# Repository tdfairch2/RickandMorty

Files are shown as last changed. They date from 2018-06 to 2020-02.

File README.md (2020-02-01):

# RickandMorty
Integrating Software and Hardware, specifically the Arduino Uno and Adafruit Pro-Trinket

This project is centered around a device from the Adult Swim cartoon "Rick and Morty"

Pin locations, source file links and the functionality is all provided in the Portal Gun document

Code alterations that I implemented are in the sketch "portalGun.ino", located in the PortalGun-master folder.  My changes to the original source code are indicated with more detailed comments than were included in the original.....\\|/

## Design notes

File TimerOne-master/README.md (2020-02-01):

#TimerOne Library#

Paul Stoffregen's modified TimerOne.  This version provides 2 main benefits:

1: Optimized inline functions - much faster for the most common usage  
2: Support for more boards (including ATTiny85 except for the PWM functionality)

http://www.pjrc.com/teensy/td_libs_TimerOne.html

https://github.com/PaulStoffregen/TimerOne

Original code:

http://playground.arduino.cc/Code/Timer1

Open Source License

TimerOne is free software. You can redistribute it and/or modify it under
the terms of Creative Commons Attribution 3.0 United States License.
To view a copy of this license, visit

http://creativecommons.org/licenses/by/3.0/us/

Paul Stoffregen forked this version from an early copy of TimerOne/TimerThree
which was licensed "Creative Commons Attribution 3.0" and has maintained
the original "CC BY 3.0 US" license terms.

Other, separately developed updates to TimerOne have been released by other
authors under the GNU GPLv2 license.  Multiple copies of this library, bearing
the same name but distributed under different license terms, is unfortunately
confusing.  This copy, with nearly all the code redesigned as inline functions,
is provided under the "CC BY 3.0 US" license terms.

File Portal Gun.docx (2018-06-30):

# PortalGun

# *****All resources used were originally found at:

# https://www.thingiverse.com/thing:1100601 and from there the following link -

# https://github.com/pomeroyb/PortalGun

# I have altered the pin-outs as necessary to allow for more sounds and for better organization of the wiring*****

Code to control a Portal Gun (From Rick and Morty)

##Libraries Download and install the following libraries:

- ClickEncoder (https://github.com/0xPIT/encoder)
- Adafruit_GFX (https://github.com/adafruit/Adafruit-GFX-Library)
- Adafruit_LEDBackpack (https://github.com/adafruit/Adafruit-LED-Backpack-Library)

## Pin Definitions

If you deviate from the following definitions, you will have to change the firmware to account for that.

LED Display | Trinket Pro Pin
SCL | A5
SDA | A4
GND | GND
Vcc | 5V
Vi2c | 5V

Rotary Encoder | Trinket Pro Pin
A | A1
B | A0
GND | GND
Button | A2

LED | Trinket Pro Pin
Top Bulb | 13
Front Right | 12
Front Center | 11
Front Left | 10

## Installing Firmware

First, set up the Arduino IDE according to Adafruit (https://learn.adafruit.com/introducing-pro-trinket/setting-up-arduino-ide). Connect your Trinket Pro and make sure the bootloader is running, then click upload.

## Button Behavior

The rotary encoder has a click button, and we can detect a single click, a double click, and a hold.

- Single Click : Wakes the Trinket Pro from low power mode
- Double Click : Reset to dimension C137
- Hold : Turn off LEDs and put the Trinket Pro into a low power mode.

## Sound FX Pin Definitions

If you deviate from the following definitions, you will have to change the firmware to account for that.

FX Sound Board | Trinket Pro Pin | | Sound Effect Dimension Location For these locations you can use any sound file you want, I used VLC media files (.OGG) per the specifications by Adafruit
0 | | 0 | C136 – this is the value entered on the LED display
1 | | 1 | C135
2 | | 2 | C134
3 | | 3 | C133
4 | | 4 | C132
5 | | 5 | C131
6 | | 6 | C130
7 | | 7 | C129
8 | | 8 | C128
9 | | 9 | C127

The above listing of the pin connections between the Pro Trinket and the Sound Board is just for the sake of clarity. The small size of the main body of the Portal Gun imposed severe restrictions on the layout of the components. It was necessary to lay the boards next to each other, which allowed very few options for connections. The use of solid core wire, which by its nature is very stiff, further complicated the assembly process. So there are only six sound files in use, and the actual layout and pin connections are illustrated below.

Pro Trinket Sound Board

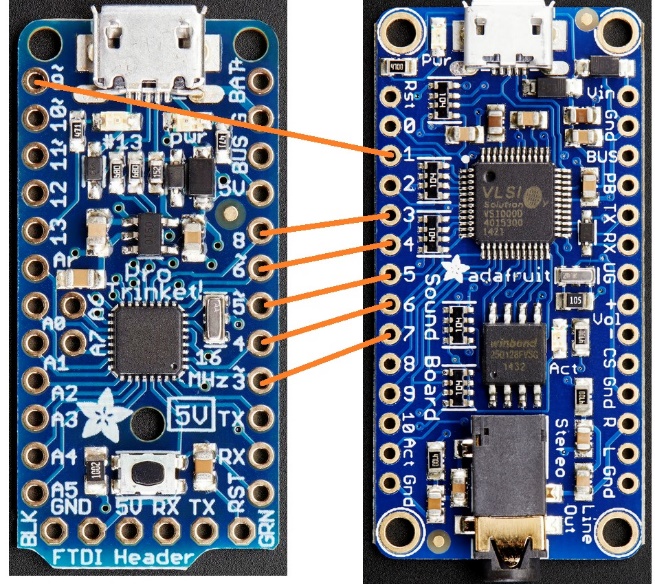
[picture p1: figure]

Wiring all of the components for this project proved to be quite a challenge.

The difficulties in assembling the circuit will probably be greatly reduced by soldering everything to a PCB instead of using wire.

## Installing Firmware

First, set up the Arduino IDE according to Adafruit (https://learn.adafruit.com/introducing-pro-trinket/setting-up-arduino-ide). Connect your Trinket Pro and make sure the bootloader is running, then click upload.

##Installing SFX You should be able to just connect the FX board to the computer, and drop the files in the "sfx" folder onto it. The files do follow a naming convention (see here (https://learn.adafruit.com/adafruit-audio-fx-sound-board/triggering-audio)), so don't change the file names unless you know what you're doing.

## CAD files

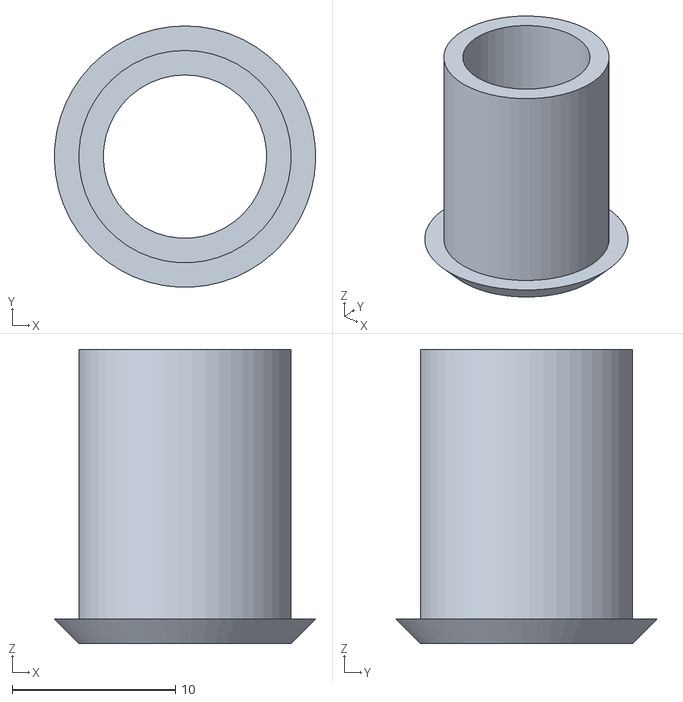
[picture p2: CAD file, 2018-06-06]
3-d print files/LEDHolder.STL
16.0 x 16.0 x 18.0

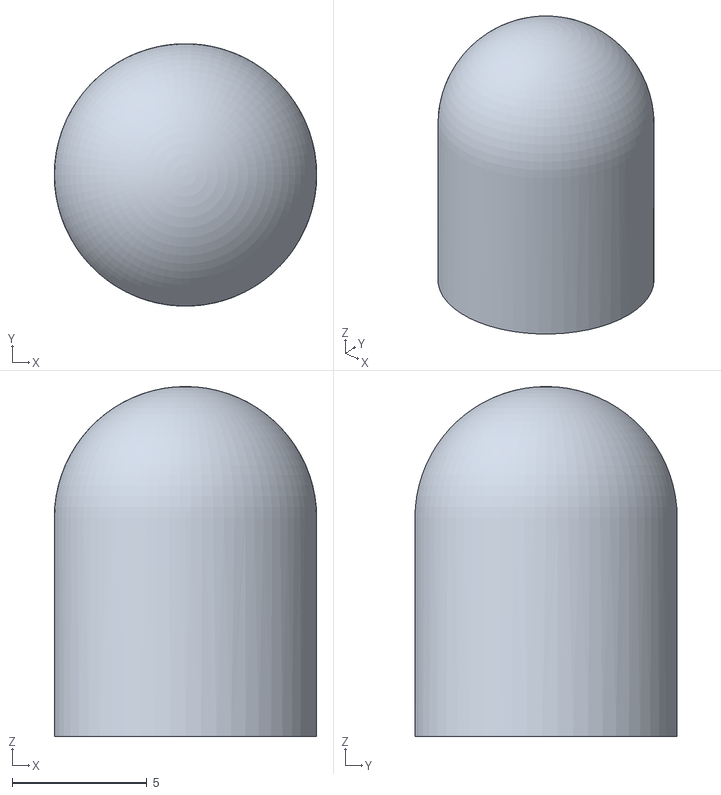
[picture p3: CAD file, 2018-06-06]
3-d print files/10mmLED.STL
9.75 x 9.75 x 13.0

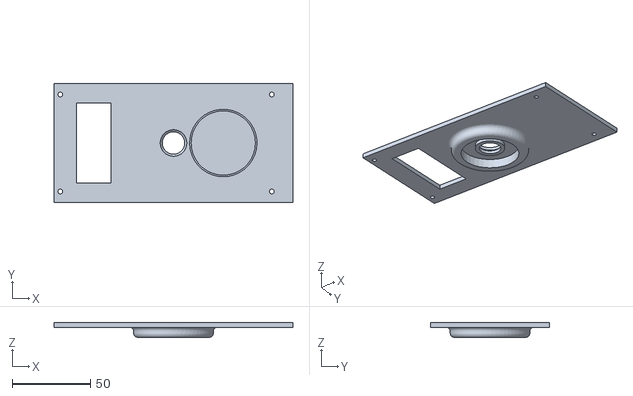
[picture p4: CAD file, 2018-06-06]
3-d print files/TopCover.stl
152.4 x 76.2 x 9.35

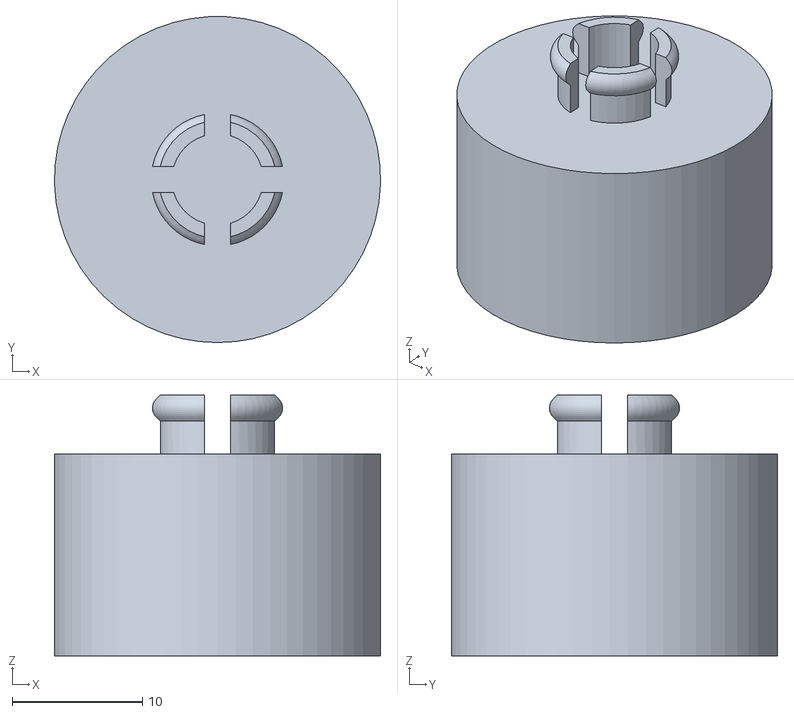
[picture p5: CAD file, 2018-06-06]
3-d print files/Knob.STL
25.0 x 25.0 x 20.0

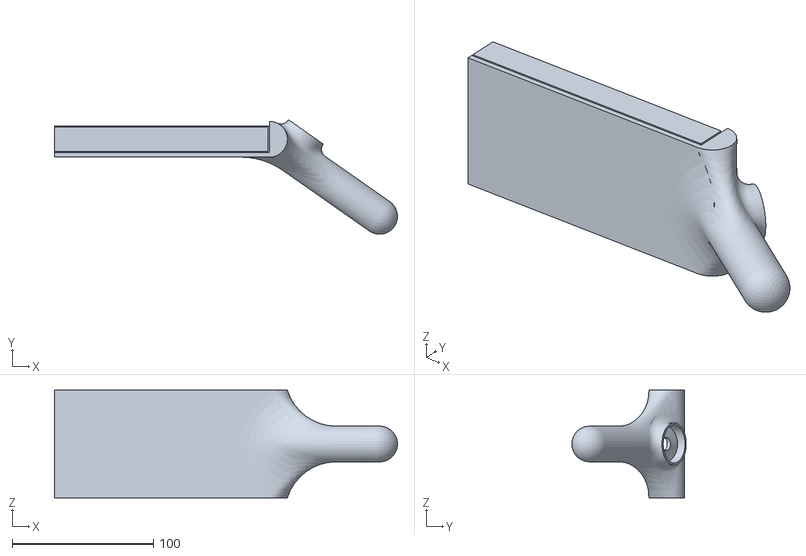
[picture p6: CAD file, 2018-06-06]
3-d print files/Body.stl
243.1 x 81.1 x 76.2

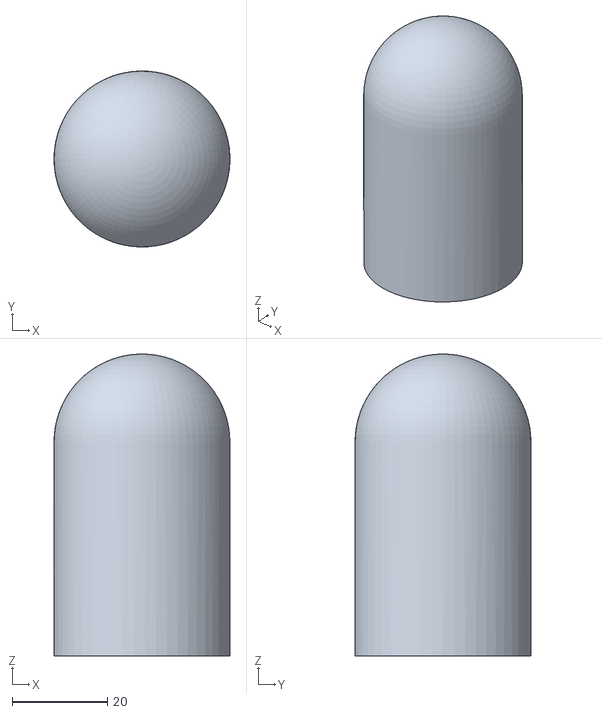
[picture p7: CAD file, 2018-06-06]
3-d print files/Bulb.stl
37.0 x 37.0 x 63.5

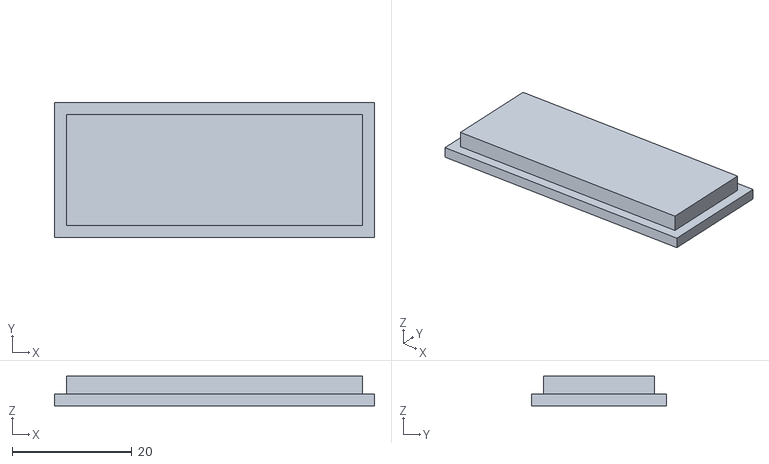
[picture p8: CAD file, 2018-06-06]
3-d print files/PrintedLEDScreen.STL
53.5 x 22.5 x 5.00

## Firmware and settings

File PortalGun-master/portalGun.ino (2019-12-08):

/* This is my very favorite project utilizing C++ programming.  I have created this repo as a record of my work but have made 
  updates to ensure inclusion in the GitHub Archive Progam, to have something as a legacy*/
#include <ClickEncoder.h>

#include <TimerOne.h>

// Code to control a Rick and Morty Portal Gun
// Written by Brandon Pomeroy, 2015

/* Modified by Terry Fairchild, 2018
  all 3-d print files and code source files -
  https://www.thingiverse.com/thing:1100601
      and -
  "People who are really serious about software should build their own hardware" - Alan Kay*/

/*
******** Required Libraries *************
  ClickEncoder - https://github.com/0xPIT/encoder
  Adafruit_GFX - https://github.com/adafruit/Adafruit-GFX-Library
  Adafruit_LEDBackpack - https://github.com/adafruit/Adafruit-LED-Backpack-Library
*/


/*
********** Required Hardware *********************
  Adafruit Pro Trinket 5V 16MHz - http://www.adafruit.com/product/2000
  LiPoly BackPack - http://www.adafruit.com/product/2124
  LiPoly Battety 3.7V - http://www.adafruit.com/products/1578
  Rotary Encoder - http://www.adafruit.com/products/377
  Metal Knob - http://www.adafruit.com/products/2056
  Quad Alphanumeric Display (Red 0.54") - http://www.adafruit.com/products/1911
  10mm Diffused Green LED (x4) - https://www.adafruit.com/products/844
  10mm Plastic Bevel LED Holder (x4) - https://www.adafruit.com/products/2171
  150 Ohm Resistor (x4) for LEDs
  Inductive Charging Set - 5V - https://www.adafruit.com/products/1407
  2.1mm Panel Mount Barrel Jack - http://www.adafruit.com/products/610
  9VDC Power Supply - http://www.adafruit.com/products/63
*/

#include <Wire.h>
#include "Adafruit_LEDBackpack.h"
#include "Adafruit_GFX.h"
#include <ClickEncoder.h>
#include <TimerOne.h>
#include <avr/sleep.h>
#include <avr/power.h>

// Set up our LED display
Adafruit_AlphaNum4 alpha4 = Adafruit_AlphaNum4();
char displayBuffer[4];
uint8_t dimensionLetter = 'C';

// Set up the click encoder
ClickEncoder *encoder;
int16_t last, value;
#define encoderPinA          A1
#define encoderPinB          A0
#define encoderButtonPin     A2

// Steps per notch can be 1, 4, or 8. If your encoder is counting
// to fast or too slow, change this!
#define stepsPerNotch        4

// Comment this line to make the encoder increment in the opposite direction
#define reverseEncoderWheel

// FX Board output delay (ms)
const int msDelay = 500;


/*************************************************************************************************************************************************************************
*                       Set up the sound fx pinouts
* The soundboard allows for only 10 ogg files because it has 10 output pins and the files stored in its memory are identified by number,
*  starting with 01 and ending with 10, depending on how many sound files are to be used.
* 
* 
* For the Pro Trinket, the sound file names are merely references.  I think they can be anything.  They are defined in the statements below.  
*    These names trigger the output pins to which they are assigned, listed next to them.
*
* The six Pro Trinket output pins available for sounds are pins 3 thru 9. Pin 8 is not labeled on the Pro Trinket so I skipped it.  For clarity each of the six pins used 
*    is connected to the corresponding numbered pin on the sound board.
*
* The numbered pin on the sound board plays whichever ogg file has that number.  i.e. sound file 'T04' is the name of an ogg audio file on the sound board.
*    Sound file T04 will be output whenever pin 04 on the sound board is triggered.  Pin 04 is connected to Trinket pin 4, and it is assigned to the variable name 'pickleRick'
*    in the sketch.  So when the sketch correctly uses the name 'pickleRick', it triggers pin 4 on the Pro Trinket which triggers pin 04 on the sound board, 
*    which causes ogg file T04 to play.
*
* Sound files T00, T01, T02, T08 and T10 are included on soundboard.  They have not been integrated into the code because I think there are fewer pinouts on the pro trinket
*    available for sound than were available on the Arduino board I used to prototype this project, and I did not wish to go to the effort to test this.
*
* Just make sure that 1) the pinouts on the Pro Trinket connect to the desired pinouts on the sound board and 2) the names of the sound files match the desired pinouts on the
*    sound board.  If you get either of these wrong you will not get the sound file you want for your dimension location
/*************************************************************************************************************************************************************************/
#define portalGunPin         3      //Portal, T03
#define pickleRick           4      //Pickle Rick, T04
#define tinyRick             5      //Tiny Rick, T05
#define peaceOot             6      //Peace oot, T06 
#define partyBiiiiitch       7      //Party bitch, T07
#define riggityWreckedSon    9      //Wrecked, T09
/************************************************************/
/************************************************************/


// Set up the Green LEDs
#define topBulbPin           13
#define frontRightPin        12
#define frontCenterPin       11
#define frontLeftPin         10
#define maximumBright        255
#define mediumBright         127
int topBulbBrightness = 255;

// Set up what we need to sleep/wake the Trinket
// Define the pins you'll use for interrupts - CHANGE THESE to match the input pins
// you are using in your project
#define NAV0_PIN A2
#define NAV1_PIN 1
#define NAV2_PIN 2


//Let us know if our Trinket woke up from sleep
volatile bool justWokeUp;


void timerIsr() {
  encoder->service();
}


void setup() {
  enablePinInterupt(NAV0_PIN);
  enablePinInterupt(NAV1_PIN);
  enablePinInterupt(NAV2_PIN);

  //Set up pin modes
  pinMode(topBulbPin, OUTPUT);
  pinMode(frontRightPin, OUTPUT);
  pinMode(frontLeftPin, OUTPUT);
  pinMode(frontCenterPin, OUTPUT);


/*************************************************************************/
/****Initialize the sound fx pinouts and topBulb to be output pins *******/
/*************************************************************************/
  pinMode(portalGunPin, OUTPUT);
  pinMode(pickleRick, OUTPUT);
  pinMode(tinyRick, OUTPUT);
  pinMode(peaceOot, OUTPUT);
  pinMode(partyBiiiiitch, OUTPUT);
  pinMode(riggityWreckedSon, OUTPUT);
/*************************************************************************/
/*************************************************************************/


  digitalWrite(frontRightPin, LOW);
  digitalWrite(frontLeftPin, LOW);
  digitalWrite(frontCenterPin, LOW);
  digitalWrite(topBulbPin, HIGH); //topBulbPin is for the plasma chamber and is illuminated until shutdown


/********************************************************************************
 * Initialize the sound fx pins to be OFF
 * Counter-intuitively when these pins are set to 'LOW' 
 * they become active, then become inactive when set to 'HIGH'.
 *******************************************************************************/
  digitalWrite(portalGunPin, HIGH);
  digitalWrite(pickleRick, HIGH);
  digitalWrite(tinyRick, HIGH);
  digitalWrite(peaceOot, HIGH);
  digitalWrite(partyBiiiiitch, HIGH);
  digitalWrite(riggityWreckedSon, HIGH);
/******************************************************************************
 ******************************************************************************/


  encoderSetup();
  alpha4.begin(0x70);  // pass in the address for the LED display

  justWokeUp = false;

}


void loop() {
  if (justWokeUp) {


/***************************************************************************
*  At 'wake-up', sound fx are turned off by setting to HIGH
* Seems redundant but otherwise they trigger constantly
***************************************************************************/
    digitalWrite(portalGunPin, HIGH);
    digitalWrite(pickleRick, HIGH);
    digitalWrite(tinyRick, HIGH);
    digitalWrite(peaceOot, HIGH);
    digitalWrite(partyBiiiiitch, HIGH);
    digitalWrite(riggityWreckedSon, HIGH);
/***************************************************************************/
/***************************************************************************/


    digitalWrite(frontRightPin, LOW);
    digitalWrite(frontLeftPin, LOW);
    digitalWrite(frontCenterPin, LOW);
    digitalWrite(topBulbPin, HIGH);
    justWokeUp = false;
  }

  ClickEncoder::Button b = encoder->getButton();
  switch (b) {
    case ClickEncoder::Held:
      // Holding the button will put your trinket to sleep.
      // The trinket will wake on the next button press
      alpha4.clear();
      alpha4.writeDigitAscii(0, 'R');
      alpha4.writeDigitAscii(1, 'I');
      alpha4.writeDigitAscii(2, 'C');
      alpha4.writeDigitAscii(3, 'K');
      digitalWrite(frontRightPin, LOW);
      digitalWrite(frontLeftPin, LOW);
      digitalWrite(frontCenterPin, LOW);
      digitalWrite(topBulbPin, LOW);


/***************************************************************************
*  At shut-down, sound fx are turned off
****************************************************************************/
      digitalWrite(portalGunPin, HIGH);
      digitalWrite(pickleRick, HIGH);
      digitalWrite(tinyRick, HIGH);
      digitalWrite(peaceOot, HIGH);
      digitalWrite(partyBiiiiitch, HIGH);
      digitalWrite(riggityWreckedSon, HIGH);
/***************************************************************************
***************************************************************************/


      alpha4.writeDisplay();
      delay(2000);
      alpha4.clear();
      alpha4.writeDisplay();


/**************************************************************************
*           Original code block above displayed "RICK" only
*  The following modification scrolls "RICK and MORTY" during shutdown
/**************************************************************************/
      alpha4.clear();
      alpha4.writeDigitAscii(0, 'a');
      alpha4.writeDigitAscii(1, 'n');
      alpha4.writeDigitAscii(2, 'd');
      alpha4.writeDigitAscii(3, ' ');
      alpha4.writeDisplay();
      delay(750);
      alpha4.clear();
      alpha4.writeDisplay();
      delay(500);

      alpha4.clear();
      alpha4.writeDigitAscii(0, 'M');
      alpha4.writeDigitAscii(1, 'O');
      alpha4.writeDigitAscii(2, 'R');
      alpha4.writeDigitAscii(3, 'T');
      alpha4.writeDisplay();
      delay(500);

      alpha4.clear();
      alpha4.writeDigitAscii(0, 'O');
      alpha4.writeDigitAscii(1, 'R');
      alpha4.writeDigitAscii(2, 'T');
      alpha4.writeDigitAscii(3, 'Y');
      alpha4.writeDisplay();
      delay(500);
      
      alpha4.clear();
      alpha4.writeDigitAscii(0, 'R');
      alpha4.writeDigitAscii(1, 'T');
      alpha4.writeDigitAscii(2, 'Y');
      alpha4.writeDigitAscii(3, ' ');
      alpha4.writeDisplay();
      delay(500);

      alpha4.clear();
      alpha4.writeDigitAscii(0, 'T');
      alpha4.writeDigitAscii(1, 'Y');
      alpha4.writeDigitAscii(2, ' ');
      alpha4.writeDigitAscii(3, ' ');
      alpha4.writeDisplay();
      delay(500);


      alpha4.clear();
      alpha4.writeDigitAscii(0, 'Y');
      alpha4.writeDigitAscii(1, ' ');
      alpha4.writeDigitAscii(2, ' ');
      alpha4.writeDigitAscii(3, ' ');
      alpha4.writeDisplay();
      delay(500);
      alpha4.clear();
      alpha4.writeDisplay();
      delay(1000);
/***********************************************************************************
************************************************************************************/


      justWokeUp = true;
      goToSleep();
      break;

    case ClickEncoder::Clicked:
      // When the encoder wheel is single clicked


/***************************************************************************************
* Check if this is a sound fx dimension
* Sound will trigger at specific locations when entered AND button is pressed once 
* File names are listed in the comments above when the sound files are defined 
* When triggered the output requires a delay of at least 200ms
***************************************************************************************/
      if (dimensionLetter == 'C' && value == 136){
                  delay (500);
                  digitalWrite(peaceOot, LOW);
                  delay (500);
                  digitalWrite(peaceOot, HIGH);
      }

      else if (dimensionLetter == 'C' && value == 135){
                  delay (500);
                  digitalWrite(tinyRick, LOW);
                  delay (500);
                  digitalWrite(tinyRick, HIGH);
      }
      else if (dimensionLetter == 'C' && value == 134){
                  delay (500);
                  digitalWrite(pickleRick, LOW);
                  delay (500);
                  digitalWrite(pickleRick, HIGH);
      }
      else if (dimensionLetter == 'C' && value == 133){
                  delay (500);
                  digitalWrite(partyBiiiiitch, LOW);
                  delay (500);
                  digitalWrite(partyBiiiiitch, HIGH);
      }
      else if (dimensionLetter == 'C' && value == 132){
                  delay (500);
                  digitalWrite(riggityWreckedSon, LOW);
                  delay (500);
                  digitalWrite(riggityWreckedSon, HIGH);
      }
/************************************************************************************
* If a sound fx location is not selected, run the Firing Sequence.
* Flash the LED's and the word FIRE five times simultaneously
*  then four times flash the LED's only  
************************************************************************************/
        else {                                              //
        digitalWrite(portalGunPin, LOW);                    //
        delay(500);                                         //
        digitalWrite(portalGunPin, HIGH);                   //
                                                            //
      for (int i = 1; i <= 5; i++) {                        //
        alpha4.clear();                                     //
        alpha4.writeDigitAscii(0, 'F');                     //
        alpha4.writeDigitAscii(1, 'I');                     //
        alpha4.writeDigitAscii(2, 'R');                     //
        alpha4.writeDigitAscii(3, 'E');                     //
        digitalWrite(frontRightPin, LOW);                   //
        digitalWrite(frontLeftPin, LOW);                    //
        digitalWrite(frontCenterPin, LOW);                  //
                                                            //
        alpha4.writeDisplay();                              //
        delay(250);                                         //
        alpha4.clear();                                     //
        digitalWrite(frontRightPin, HIGH);                  //
        digitalWrite(frontLeftPin, HIGH);                   //
        digitalWrite(frontCenterPin, HIGH);                 //
                                                            //
        alpha4.writeDisplay();                              //
        delay(250);                                         //
      }                                                     //
      for (int i = 1; i <= 4; i++) {                        //
        alpha4.clear();                                     //
        digitalWrite(frontRightPin, LOW);                   //
        digitalWrite(frontLeftPin, LOW);                    //
        digitalWrite(frontCenterPin, LOW);                  //
                                                            //
        alpha4.writeDisplay();                              //
        delay(250);                                         //
        alpha4.clear();                                     //
        digitalWrite(frontRightPin, HIGH);                  //
        digitalWrite(frontLeftPin, HIGH);                   //
        digitalWrite(frontCenterPin, HIGH);                 //
                                                            //
        alpha4.writeDisplay();                              //
        delay(250);                                         //
        digitalWrite(frontRightPin, LOW);                   //
        digitalWrite(frontLeftPin, LOW);                    //
        digitalWrite(frontCenterPin, LOW);                  //
                                                            //
        }                                                   //
      }                                                     //
/***************************************************************************
****************************************************************************/


      break;
    case ClickEncoder::DoubleClicked:
      //If you double click the button, it sets the dimension to C137
      dimensionLetter = 'C';
      value = 137;
      break;

    case ClickEncoder::Open:
      // The dimension will increment from 0-999, then roll over to the next
      // letter. (A999 -> B000)
      updateDimension();
      break;
  }
}


void encoderSetup() {
  // set up encoder
  encoder = new ClickEncoder(encoderPinA, encoderPinB, encoderButtonPin, stepsPerNotch);
  encoder->setAccelerationEnabled(true);

  Timer1.initialize(1000);
  Timer1.attachInterrupt(timerIsr);
  last = -1;
  value = 137;
}


void updateDimension() {
#ifdef reverseEncoderWheel
  value -= encoder->getValue();
#endif

#ifndef reverseEncoderWheel
  value += encoder->getValue();
#endif

  if (value != last) {
    if (value > 999) {
      value = 0;
      if (dimensionLetter == 'Z') {
        dimensionLetter = 'A';
      } else {
        dimensionLetter ++;
      }
    } else if ( value < 0 ) {
      value = 999;
      if (dimensionLetter == 'A') {
        dimensionLetter = 'Z';
      } else {
        dimensionLetter --;
      }
    }
    last = value;
  }

  sprintf(displayBuffer, "%03i", value);
  alpha4.clear();
  alpha4.writeDigitAscii(0, dimensionLetter);
  alpha4.writeDigitAscii(1, displayBuffer[0]);
  alpha4.writeDigitAscii(2, displayBuffer[1]);
  alpha4.writeDigitAscii(3, displayBuffer[2]);

  alpha4.writeDisplay();
}

/*
  ============== Sleep/Wake Methods ==================
  ====================================================
*/

// Most of this code comes from seanahrens on the adafruit forums
// http://forums.adafruit.com/viewtopic.php?f=25&t=59392#p329418


void enablePinInterupt(byte pin)
{
  *digitalPinToPCMSK(pin) |= bit (digitalPinToPCMSKbit(pin));  // enable pin
  PCIFR  |= bit (digitalPinToPCICRbit(pin)); // clear any outstanding interrupt
  PCICR  |= bit (digitalPinToPCICRbit(pin)); // enable interrupt for the group
}

void goToSleep()
{
  // The ATmega328 has five different sleep states.
  // See the ATmega 328 datasheet for more information.
  // SLEEP_MODE_IDLE -the least power savings
  // SLEEP_MODE_ADC
  // SLEEP_MODE_PWR_SAVE
  // SLEEP_MODE_STANDBY
  // SLEEP_MODE_PWR_DOWN -the most power savings
  // I am using the deepest sleep mode from which a
  // watchdog timer interrupt can wake the ATMega328




  set_sleep_mode(SLEEP_MODE_PWR_DOWN); // Set sleep mode.
  sleep_enable(); // Enable sleep mode.
  sleep_mode(); // Enter sleep mode.
  // After waking the code continues
  // to execute from this point.

  sleep_disable(); // Disable sleep mode after waking.
}

ISR (PCINT0_vect) // handle pin change interrupt for D8 to D13 here
{
  // if I wired up D8-D13 then I'd need some code here
}

ISR (PCINT1_vect) // handle pin change interrupt for A0 to A5 here // NAV0
{
  /* This will bring us back from sleep. */

  /* We detach the interrupt to stop it from
     continuously firing while the interrupt pin
     is low.
  */

  detachInterrupt(0);

}

ISR (PCINT2_vect) // handle pin change interrupt for D0 to D7 here // NAV1, NAV2
{
  // Check it was NAV1 or NAV2 and nothing else
}


/*
  ============== Testing Methods ==================
  =================================================
uncomment this to make the display run through a test at startup
It may prove useful, it was included in the original code from Brandon Pomeroy


displayTest();


void displayTest() {
  alpha4.writeDigitRaw(3, 0x0);
  alpha4.writeDigitRaw(0, 0xFFFF);
  alpha4.writeDisplay();
  delay(200);
  alpha4.writeDigitRaw(0, 0x0);
  alpha4.writeDigitRaw(1, 0xFFFF);
  alpha4.writeDisplay();
  delay(200);
  alpha4.writeDigitRaw(1, 0x0);
  alpha4.writeDigitRaw(2, 0xFFFF);
  alpha4.writeDisplay();
  delay(200);
  alpha4.writeDigitRaw(2, 0x0);
  alpha4.writeDigitRaw(3, 0xFFFF);
  alpha4.writeDisplay();
  delay(200);

  alpha4.clear();
  alpha4.writeDisplay();

  // display every character,
  for (uint8_t i = '!'; i <= 'z'; i++) {
    alpha4.writeDigitAscii(0, i);
    alpha4.writeDigitAscii(1, i + 1);
    alpha4.writeDigitAscii(2, i + 2);
    alpha4.writeDigitAscii(3, i + 3);
    alpha4.writeDisplay();
    delay(300);
  }
}*/


/* Some quotes:

“Nobody exists on purpose, nobody belongs anywhere, everybody's gonna die.  Come watch TV.”
          -	Morty Smith, "Rixty Minutes"


“It’s a never-ending fart joke wrapped around a studied look into nihilism.”
          -	Kayla Cobb, ‘Rick and Morty’ Is Better When It Embraces Its Strong Women’, 
          Decider, Oct. 4, 2017


Rick: Great, now I have to take over a whole Planet because of your Stupid Boobs!

Rick: [knife at his throat] Are you a simulation Morty? Are you, you little bitch? Are you a simulation Morty?
Morty: No!
Rick: Ah right. Sorry Morty. You're a good kid. You're a good kid Morty.
[Falls asleep]
Morty: What? Oh God! What a life...

Chief: Well done, Babylegs, you've learned a valuable lesson about teamwork and accepting your own limitations. Now get the fuck out!

Mr Poopy Butthole: Oooh weee! Is this how I die?

Plutonian: Is everyone in your Family an Idiot?
Morty: For sure me and my Dad are!
 


Dr. Wong:  Why didn't you want to come here?
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

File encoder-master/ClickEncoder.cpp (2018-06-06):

// ----------------------------------------------------------------------------
// Rotary Encoder Driver with Acceleration
// Supports Click, DoubleClick, Long Click
//
// (c) 2010 karl@pitrich.com
// (c) 2014 karl@pitrich.com
//
// Timer-based rotary encoder logic by Peter Dannegger
// http://www.mikrocontroller.net/articles/Drehgeber
// ----------------------------------------------------------------------------

#include "ClickEncoder.h"

// ----------------------------------------------------------------------------
// Button configuration (values for 1ms timer service calls)
//
#define ENC_BUTTONINTERVAL    50  // check button every 10 milliseconds, also debouce time
#define ENC_DOUBLECLICKTIME  1000  // second click within 600ms
#define ENC_HOLDTIME        2000  // report held button after 1.2s

// ----------------------------------------------------------------------------
// Acceleration configuration (for 1000Hz calls to ::service())
//
#define ENC_ACCEL_TOP      3072   // max. acceleration: *12 (val >> 8)
#define ENC_ACCEL_INC        25
#define ENC_ACCEL_DEC         2

// ----------------------------------------------------------------------------

#if ENC_DECODER != ENC_NORMAL
#  ifdef ENC_HALFSTEP
     // decoding table for hardware with flaky notch (half resolution)
     const int8_t ClickEncoder::table[16] __attribute__((__progmem__)) = {
       0, 0, -1, 0, 0, 0, 0, 1, 1, 0, 0, 0, 0, -1, 0, 0
     };
#  else
     // decoding table for normal hardware
     const int8_t ClickEncoder::table[16] __attribute__((__progmem__)) = {
       0, 1, -1, 0, -1, 0, 0, 1, 1, 0, 0, -1, 0, -1, 1, 0
     };
#  endif
#endif

// ----------------------------------------------------------------------------

ClickEncoder::ClickEncoder(uint8_t A, uint8_t B, uint8_t BTN, uint8_t stepsPerNotch, bool active)
  : doubleClickEnabled(true), accelerationEnabled(true),
    delta(0), last(0), acceleration(0),
    button(Open), steps(stepsPerNotch),
    pinA(A), pinB(B), pinBTN(BTN), pinsActive(active)
{
  uint8_t configType = (pinsActive == LOW) ? INPUT_PULLUP : INPUT;
  pinMode(pinA, configType);
  pinMode(pinB, configType);
  pinMode(pinBTN, configType);

  if (digitalRead(pinA) == pinsActive) {
    last = 3;
  }

  if (digitalRead(pinB) == pinsActive) {
    last ^=1;
  }
}

// ----------------------------------------------------------------------------
// call this every 1 millisecond via timer ISR
//
void ClickEncoder::service(void)
{
  bool moved = false;
  unsigned long now = millis();

  if (accelerationEnabled) { // decelerate every tick
    acceleration -= ENC_ACCEL_DEC;
    if (acceleration & 0x8000) { // handle overflow of MSB is set
      acceleration = 0;
    }
  }

#if ENC_DECODER == ENC_FLAKY
  last = (last << 2) & 0x0F;

  if (digitalRead(pinA) == pinsActive) {
    last |= 2;
  }

  if (digitalRead(pinB) == pinsActive) {
    last |= 1;
  }

  uint8_t tbl = pgm_read_byte(&table[last]);
  if (tbl) {
    delta += tbl;
    moved = true;
  }
#elif ENC_DECODER == ENC_NORMAL
  int8_t curr = 0;

  if (digitalRead(pinA) == pinsActive) {
    curr = 3;
  }

  if (digitalRead(pinB) == pinsActive) {
    curr ^= 1;
  }

  int8_t diff = last - curr;

  if (diff & 1) {            // bit 0 = step
    last = curr;
    delta += (diff & 2) - 1; // bit 1 = direction (+/-)
    moved = true;
  }
#else
# error "Error: define ENC_DECODER to ENC_NORMAL or ENC_FLAKY"
#endif

  if (accelerationEnabled && moved) {
    // increment accelerator if encoder has been moved
    if (acceleration <= (ENC_ACCEL_TOP - ENC_ACCEL_INC)) {
      acceleration += ENC_ACCEL_INC;
    }
  }

  // handle button
  //
#ifndef WITHOUT_BUTTON
  if (pinBTN > 0 // check button only, if a pin has been provided
      && (now - lastButtonCheck) >= ENC_BUTTONINTERVAL) // checking button is sufficient every 10-30ms
  {
    lastButtonCheck = now;

    if (digitalRead(pinBTN) == pinsActive) { // key is down
      keyDownTicks++;
      if (keyDownTicks > (ENC_HOLDTIME / ENC_BUTTONINTERVAL)) {
        button = Held;
      }
    }

    if (digitalRead(pinBTN) == !pinsActive) { // key is now up
      if (keyDownTicks /*> ENC_BUTTONINTERVAL*/) {
        if (button == Held) {
          button = Released;
          doubleClickTicks = 0;
        }
        else {
          #define ENC_SINGLECLICKONLY 1
          if (doubleClickTicks > ENC_SINGLECLICKONLY) {   // prevent trigger in single click mode
            if (doubleClickTicks < (ENC_DOUBLECLICKTIME / ENC_BUTTONINTERVAL)) {
              button = DoubleClicked;
              doubleClickTicks = 0;
            }
          }
          else {
            doubleClickTicks = (doubleClickEnabled) ? (ENC_DOUBLECLICKTIME / ENC_BUTTONINTERVAL) : ENC_SINGLECLICKONLY;
          }
        }
      }

      keyDownTicks = 0;
    }

    if (doubleClickTicks > 0) {
      doubleClickTicks--;
      if (--doubleClickTicks == 0) {
        button = Clicked;
      }
    }
  }
#endif // WITHOUT_BUTTON

}

// ----------------------------------------------------------------------------

int16_t ClickEncoder::getValue(void)
{
  int16_t val;

  cli();
  val = delta;

  if (steps == 2) delta = val & 1;
  else if (steps == 4) delta = val & 3;
  else delta = 0; // default to 1 step per notch

  sei();

  if (steps == 4) val >>= 2;
  if (steps == 2) val >>= 1;

  int16_t r = 0;
  int16_t accel = ((accelerationEnabled) ? (acceleration >> 8) : 0);

  if (val < 0) {
    r -= 1 + accel;
  }
  else if (val > 0) {
    r += 1 + accel;
  }

  return r;
}

// ----------------------------------------------------------------------------

#ifndef WITHOUT_BUTTON
ClickEncoder::Button ClickEncoder::getButton(void)
{
  ClickEncoder::Button ret = button;
  if (button != ClickEncoder::Held) {
    button = ClickEncoder::Open; // reset
  }
  return ret;
}
#endif

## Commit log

2018-06-06 Update README.md
    Links to my sources for code and 3-d printer files, specific pin locations and basic functionality
2018-06-06 Arduino sketch file
    This file has the functionality for the portal gun. Sound files need to be added to the Adafruit Sound f/x board locally. Any sound file will work via drag-and-drop directly to the board, but Adafrui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
